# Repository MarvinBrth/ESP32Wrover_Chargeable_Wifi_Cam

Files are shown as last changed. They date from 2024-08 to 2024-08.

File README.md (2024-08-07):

# ESP32Wrover_Chargeable_Wifi_Cam
<div align="left">
- Created with KiCad
  
- Voltage regulator: Converts 5V to 3.3V for the microcontroller (MCU) and other voltage regulators for the camera
  
- MCU: ESP32-WROVER-E N8R8
  
- USB-C: For programming the microcontroller and charging the batteries
  
- Camera connection: For the 2MP OV2640 camera
  
- Automatic programming circuit: Allows programming without manual reset.
  
-  2 x 18560 Akkus

Schematic:

Wifi_Camera

Layout:

Layout

3D-Model:

3D-Modell

Fusion 360:

Fusion360_

Real life:

test

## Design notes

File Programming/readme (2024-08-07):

It can be easily programmed using the Arduino IDE. For detailed instructions, please refer to this https://randomnerdtutorials.com/getting-started-freenove-esp32-wrover-cam/.

The LEDs connected to the CBUS pins can be configured using the FT_PROG utility. You can download the software from https://ftdichip.com/utilities/

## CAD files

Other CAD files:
3D-Model/Camera Gehäuse v12.f3z

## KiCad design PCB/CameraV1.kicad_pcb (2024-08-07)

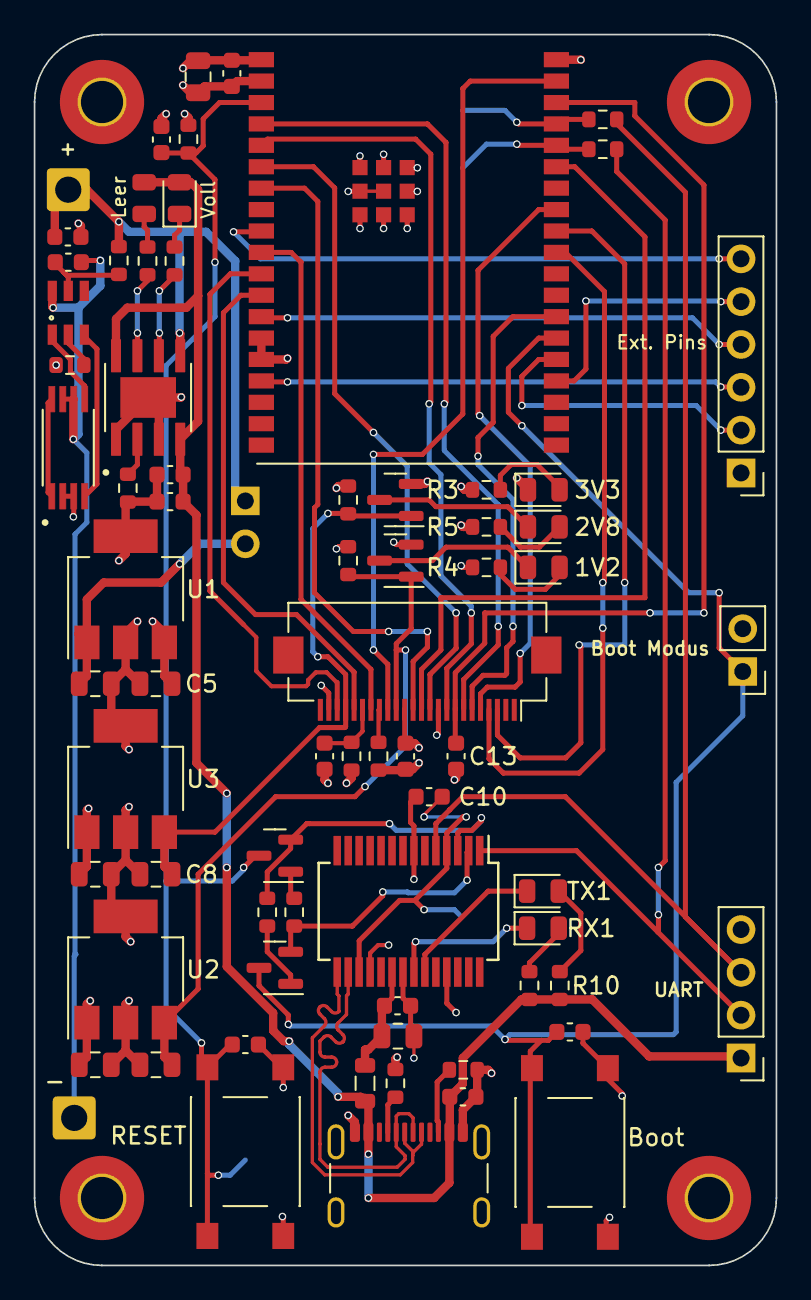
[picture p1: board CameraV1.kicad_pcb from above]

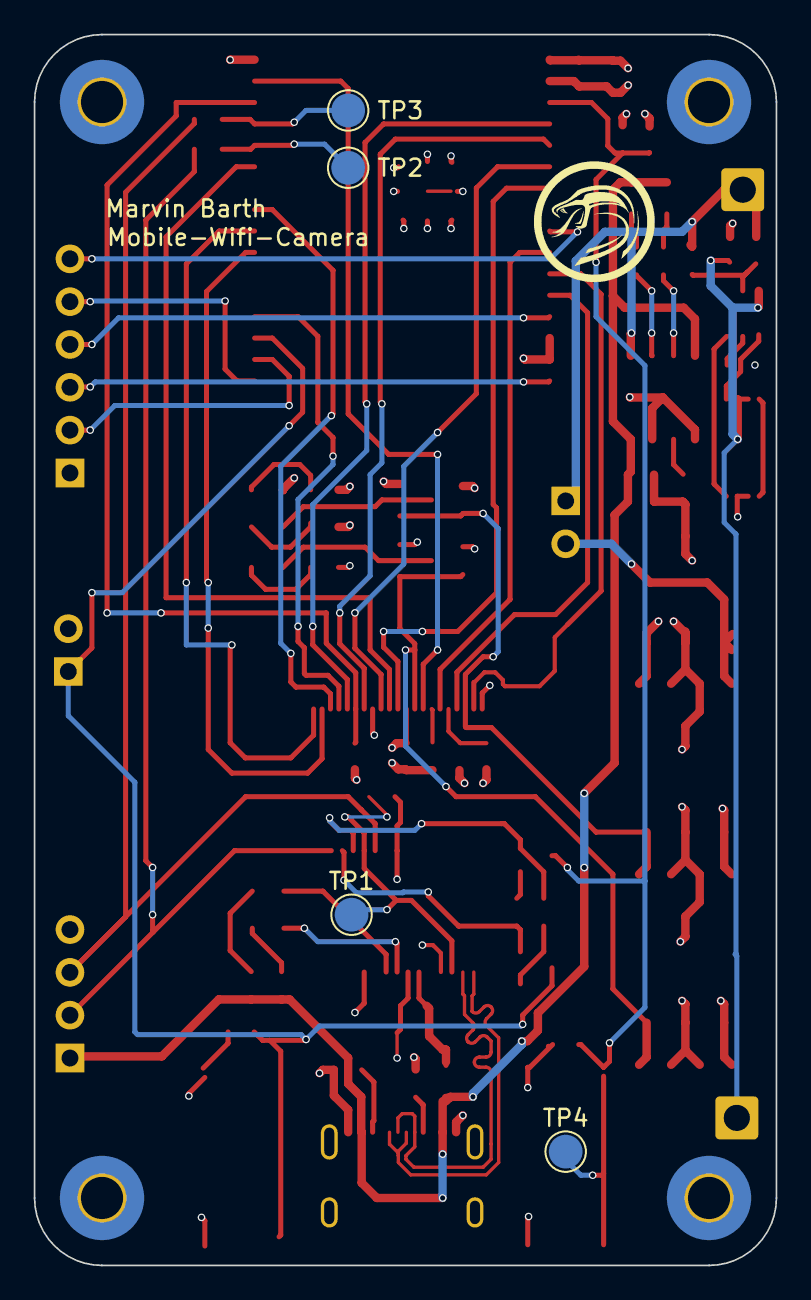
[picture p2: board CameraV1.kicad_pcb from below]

Board: 4 copper layers, 44.0 x 73.0 mm, 81 parts (4 on the bottom side), 63 nets.

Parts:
1V2, 2V8, 3V3: Blue; D_0805_2012Metric
+: 10uF; C_0603_1608Metric
-: Bat-; SolderWire-0.75sqmm_1x01_D1.25mm_OD2.3mm
Boot: SW_Push; SW_Push_1P1T_NO_6x6mm_H9.5mm
Boot Modus: Conn_01x02; PinHeader_1x02_P2.54mm_Vertical
C1, C2, C3, C5, C6, C8: 1uF; C_0805_2012Metric
C4: 10nF; C_0603_1608Metric
C7: 4.7uF; C_0805_2012Metric
C9, C10, C12, C14, C17, C18, C19, C20, C23: 100nF; C_0603_1608Metric
C11: 1uF; C_0603_1608Metric
C13: 15pF; C_0603_1608Metric
C15: 22uF; C_0805_2012Metric
C16: 22uF; C_0603_1608Metric
Ext. Pins: Conn_01x06; PinHeader_1x06_P2.54mm_Vertical
FB1: 1k; L_0805_2012Metric
H1, H2, H3, H4: MountingHole_Pad; MountingHole_2.5mm_Pad_TopBottom
H5: Bat+; SolderWire-0.75sqmm_1x01_D1.25mm_OD2.3mm
J1: USB_C_Receptacle_USB2.0; USB_C_Receptacle_GCT_USB4105-xx-A_16P_TopMnt_Horizontal
J4: Conn_01x24; Hirose_FH12-24S-0.5SH_1x24-1MP_P0.50mm_Horizontal
J6: Conn_01x02; PinHeader_1x02_P2.54mm_Vertical
Leer: D7; D_0805_2012Metric
Q1, Q2, Q4, Q5: BSS138; SOT-23
Q3: FS8205A; SOP65P640X120-8N
R1, R2: 5k1R; R_0603_1608Metric
R3, R4, R5, R10, R11, R13: 1kR; R_0603_1608Metric
R6, R7, R12, R16, R21: 10kR; R_0603_1608Metric
R8, R9: 0R; R_0603_1608Metric
R14, R15, R19: 1k; R_0603_1608Metric
R17: 1.2kR; R_0603_1608Metric
R18: 4k7R; R_0603_1608Metric
R20: 100R; R_0603_1608Metric
RESET: SW_Push; SW_Push_1P1T_NO_6x6mm_H9.5mm
RX1: Blue; D_0805_2012Metric
TP1, TP2, TP3, TP4: TestPoint_Probe; TestPoint_Pad_D2.0mm
TX1: Blue; D_0805_2012Metric
U1: MCP1703Ax-330xxDB; SOT-223-3_TabPin2
U2: MCP1703Ax-120xxDB; SOT-223-3_TabPin2
U3: MCP1703Ax-280xxDB; SOT-223-3_TabPin2
U4: FT232RL; SSOP-28_5.3x10.2mm_P0.65mm
U5: ESP32-WROVER-E-N8R8
U6: TP4056; DW01 SOP127P600X175-9N
U7: DW01A; SOT23-6
UART: Conn_01x04; PinHeader_1x04_P2.54mm_Vertical
Voll: D6; D_0805_2012Metric

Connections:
+1V2: C6.1, J4.15, Q1.1 (G), R6.2, U2.3 (VO)
+2V8: C8.1, J4.21, Q2.1 (G), R7.2, U3.3 (VO)
+3V3: C1.1, C3.1, C5.1, C12.2, C14.1, C15.1, Ext. Pins.1, J4.14, R3.1, R4.1, R5.1, R12.1, R18.2, U1.3 (VO), U2.1 (VI), U3.1 (VI), U5.2 (3V3)
/Boot Option: Boot.1, Boot Modus.1, C23.1, Q5.3 (D), U5.25 (IO0)
/CAM_RST: C19.1, J4.19, R18.1
/DTR: Q5.2 (S), R16.1, U4.2 (DTR)
/ESP_RST: C11.1, C18.1, Q4.3 (D), R12.2, RESET.1, TP4.1, U5.3 (EN)
/EXT_IO2: Ext. Pins.2, U5.24 (IO2)
/EXT_IO13: Ext. Pins.3, U5.16 (IO13)
/EXT_IO14: Ext. Pins.4, U5.13 (IO14)
/EXT_IO15: Ext. Pins.5, U5.23 (IO15)
/EXT_IO33: Ext. Pins.6, U5.9 (IO33)
/HREF: J4.16, U5.37 (IO23)
/OUT+: C2.1, J6.2, U1.1 (VI)
/PCLK: C13.2, J4.8, U5.36 (IO22)
/RTS: Q4.2 (S), R21.1, U4.3 (RTS)
/RX_ESP: R8.2, TP2.1, U5.34 (RXD0)
/RX_FT232: R9.1, U4.5 (RXD), UART.3
/RX_LED: RX1.1 (K), U4.22 (CBUS1)
/SIOC: J4.20, U5.12 (IO27)
/SIOD: J4.22, U5.11 (IO26)
/TX_ESP: R9.2, TP3.1, U5.35 (TXD0)
/TX_FT232: R8.1, U4.1 (TXD), UART.2
/TX_LED: TX1.1 (K), U4.23 (CBUS0)
/USB D+: J1.A6 (D+), J1.B6 (D+), U4.15 (USBD+)
/USB D-: J1.A7 (D-), J1.B7 (D-), U4.16 (USBD-)
/VBUS_5V: C4.1, C16.1, C17.1, FB1.1, J1.A4 (VBUS), J1.A9 (VBUS), J1.B4 (VBUS), J1.B9 (VBUS), Leer.2 (A), R10.2, R11.2, U6.4 (VCC), U6.8 (CE), UART.1, Voll.2 (A)
/VSYNC: J4.18, U5.10 (IO25)
/XCLK: J4.12, U5.33 (IO21)
/Y2: J4.6, U5.26 (IO4)
/Y3: J4.4, U5.29 (IO5)
/Y4: J4.3, U5.30 (IO18)
/Y5: J4.5, U5.31 (IO19)
/Y6: J4.7, U5.4 (SENSOR_VP)
/Y7: J4.9, U5.5 (SENSOR_VN)
/Y8: J4.11, U5.6 (IO34)
/Y9: J4.13, U5.7 (IO35)
GND: 3V3.1 (K), +.2, Boot.2, Boot Modus.2, C1.2, C2.2, C3.2, C4.2, C5.2, C6.2, C7.2, C8.2, C9.2, C10.2, C11.2, C12.1, C13.1, C14.2, C15.2, C16.2, C17.2, C18.2, C19.2, C23.2, H1.1, H2.1, H3.1, H4.1, J1.A1 (GND), J1.A12 (GND), J1.B1 (GND), J1.B12 (GND), J1.S1 (SHIELD), J4.10, J4.23, Q1.2 (S), Q2.2 (S), Q3.2, Q3.3, R1.2, R2.2, R6.1, R7.1, R13.1, R17.2, R19.2, RESET.2, U1.2 (GND), U2.2 (GND), U3.2 (GND), U4.7 (GND), U4.18 (GND), U4.21 (GND), U4.25 (AGND), U5.1 (GND), U5.14 (IO12), U5.15 (GND), U5.38 (GND), U5.39_1 (EXP), U5.39_2 (EXP), U5.39_3 (EXP), U5.39_4 (EXP), U5.39_5 (EXP), U5.39_6 (EXP), U5.39_7 (EXP), U5.39_8 (EXP), U5.39_9 (EXP), U6.1 (TEMP), U6.3 (GND), U6.9 (EP), UART.4
unnamed: 1V2.2 (A), R4.2
unnamed: 1V2.1 (K), Q1.3 (D)
unnamed: 2V8.2 (A), R5.2
unnamed: 2V8.1 (K), Q2.3 (D)
unnamed: 3V3.2 (A), R3.2
unnamed: J1.A5 (CC1), R2.1
unnamed: J1.B5 (CC2), R1.1
unnamed: J4.17, R13.2
unnamed: +.1, H5.1, J6.1, R20.2, U6.5 (BAT)
unnamed: Leer.1 (K), R15.2
unnamed: Q4.1 (G), R16.2
unnamed: Q5.1 (G), R21.2
unnamed: R11.1, RX1.2 (A)
unnamed: R10.1, TX1.2 (A)
unnamed: C10.1, TP1.1, U4.4 (VCCIO), U4.17 (3V3OUT)
unnamed: C7.1, C9.1, FB1.2, U4.20 (VCC)
unnamed: R17.1, U6.2 (PROG)
unnamed: R15.1, U6.7 (~CHRG)
unnamed: R14.1, U6.6 (~STDBY)
unnamed: R19.1, U7.2 (CS)
unnamed: -.1, C20.2, Q3.6, Q3.7, U7.6 (GND)
unnamed: Q3.4, U7.3 (OC)
unnamed: Q3.5, U7.1 (OD)
unnamed: C20.1, R20.1, U7.5 (VCC)
unnamed: R14.2, Voll.1 (K)

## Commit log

2024-08-07 Add files via upload
    Erstellt mit KiCad.
    Spannungsregler: Wandelt 5V auf 3.3V für den Mikrocontroller (MCU) und weitere Spannungsregler für die Kamera.
    MCU: ESP32-WROVER-E N8R8.
    USB-C: Für die Programmierung des Mikrocontrollers und das Laden der Akkus.
    Kameraanschluss: Für die 2MP OV2640 Kamera.
    Automatische Programmierungsschaltung: Erlaubt Programmierung ohne manuellen Reset.
2024-08-07 Create PCB
